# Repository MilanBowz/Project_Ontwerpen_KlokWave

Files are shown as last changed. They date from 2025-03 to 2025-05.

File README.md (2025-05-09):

# PO_KlokWave

## Altium

### Extra info: [Info map](Info)
- BOM
- [WAVE (alarm) source](Info/WAVE.zeewatersportsynthesizer.pdf)

### PIN mapping Arduino - ATMEGA
Gebruikt voor logica te programmeren.
https://www.circuito.io/blog/arduino-uno-pinout/

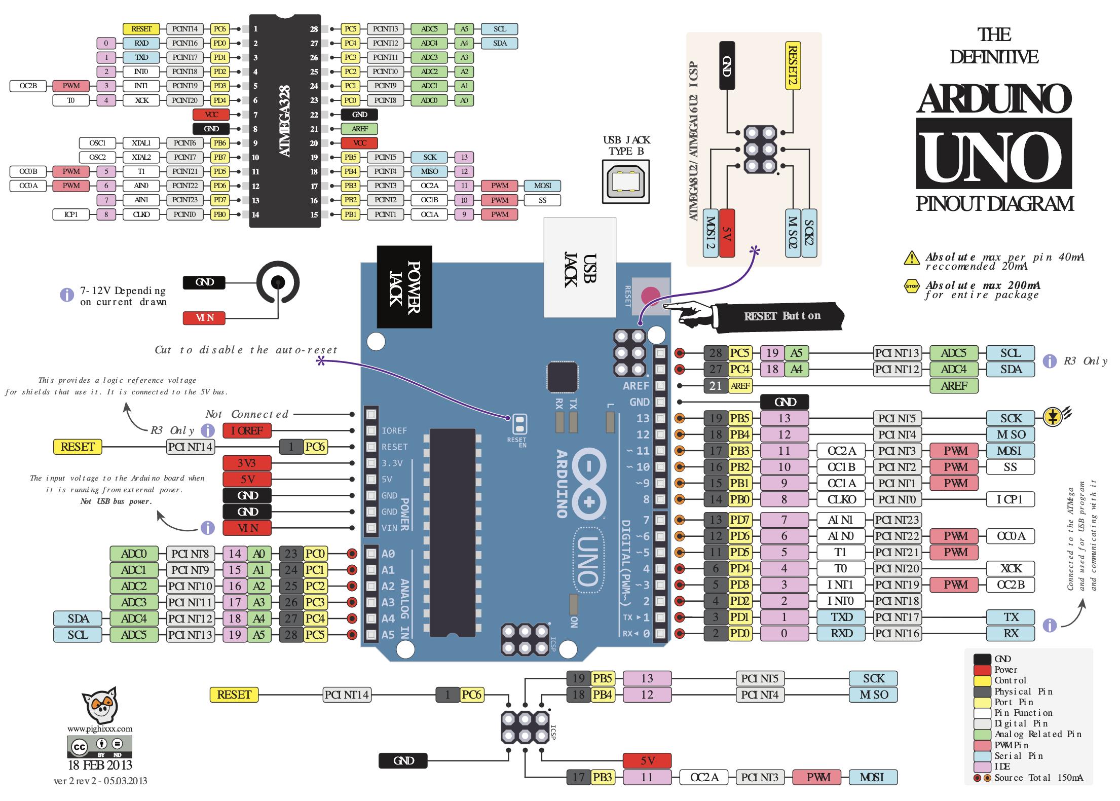
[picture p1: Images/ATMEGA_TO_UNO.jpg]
ATMEGA pins


### 8-Bit schuifregister
Gebruikt om aantal I/O pinnen in gebruikt van ATMEGA.
- hardwaretest met 7-segment display (/Tests)

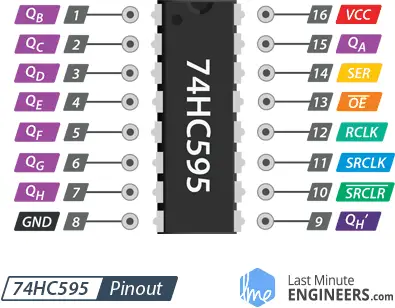
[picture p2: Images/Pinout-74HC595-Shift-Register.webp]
74HC595 pins


### Alarm (clock/ATMEGA output PB2)

Video tutorial BC547: https://www.youtube.com/watch?v=-o46f7fIX9A

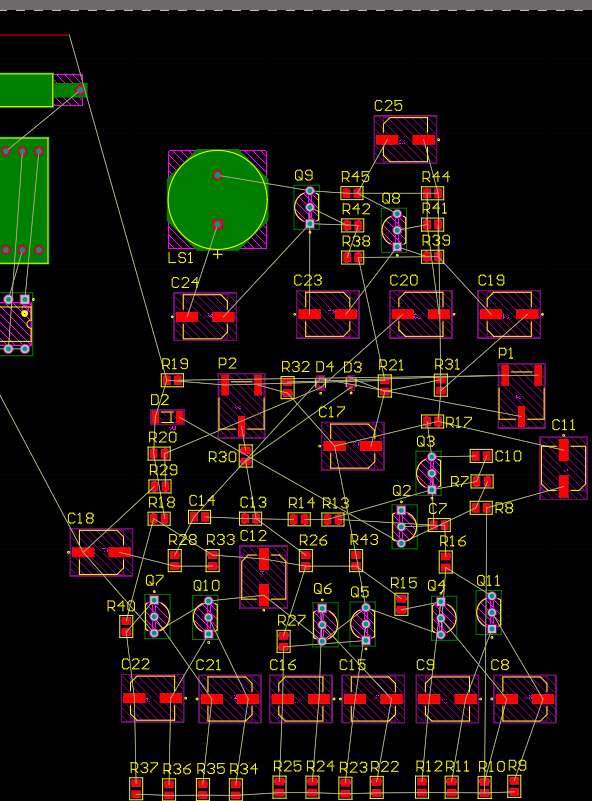
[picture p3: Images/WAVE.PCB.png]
WAVE ALARM PCB design in Altium
 

## Autodesk / 3D.Design

The design needs 2 types of holes:
- Power Supply
- Scew holes for PCB and lid

Lid is made of "~ invisible" plastic.

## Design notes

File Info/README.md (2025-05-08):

## 📦 Bill of Materials (BOM)

| **Part Number** | **Description / Value** | **Designators** | **Qty** | **Supports** |
|---|---|---|---|---|
| CR-2032/HFN | THT Coin Cell Battery, 3V, 225 mAh | B1 | 1 | DS1307+ VBAT |
| 16SEPC150MD | THT OS-CON Radial Capacitor (Polarised) | C1, C2 | 2 | VCC |
| | 220µF | C1, C2 | 2 | |
| 565R30GASS33 | THT Ceramic Capacitor (not polarised) | C3–C6 | 4 | ATMEGA |
| | 100nF | C3, C4 | 2 | VCC |
| | 22pF | C5, C6 | 2 | Y1 Crystal |
| CL21 Series 0805 | SMD 0805 Ceramic Capacitor (not polarised) | C7, C10, C13, C14 | 4 | ALARM (see pdf) |
| | 220nF, 100nF, 47nF, 4.7nF | | 4x1 | |
|  FP-OS-CON-SMT-C6-MFG | SMD Elco Capacitor (polarised) | C8–C12, C15–C25 | 15 | |
| | 100µF / 16V | | 4 | |
| | 47µF / 16V | | 6 | |
| | 10µF / 16V | | 5 | |
| 1N4007-E3/53 | THT Diode, 1A 1kV DO204AL | D1 | 1 | |
| TMMBAT48FILM | SMD Schottky Diode 40V 350mA | D2 | 1 | |
| 1N4148WT-7 | SMD Diode, 80V 125mA | D3, D4 | 2 | |
| HLMP-3301 | THT 5mm Diffused LED | DS2 | 1 | |
| — | THT DC Power Jack | J1 | 1 | |
| SA56-11EWA | THT 7-Segment Display CA | LED1–LED4 | 4 | |
| CVS-1508 | THT Speaker | LS1 | 1 | |
| 3361P-1-503GLF | SMD Trimmer Potentiometer, 50kΩ | P1, P2 | 2 | |
| BC547C | NPN Transistor, TO-92 | Q1–Q11 | 11 | |
| AC03000003000JAC00 | THT Wirewound Resistor | R3–R6, R46–R50 | 9 | |
| | 10kΩ | R5, R6, R50 | 3 | SDA, SCL, RESET |
| | 1kΩ | R4 | 1 | CTRL_ALARM |
| | 330Ω | R3 | 1 | TEST_LED |
| | 220Ω | R46–R49 | 4 | DISPLAY |
| CR0805-FX-22R6ELF | SMD 0805 Resistor | R7–R45 | 39 | ALARM (see pdf) |
| | Values: 1M, 680k, 270k, 180k, 100k, 68k (×9), 47k (×4), 39k (×2), 33k, 22k (×2), 10k (×3), 6.8k (×6), 4.7k, 2.2k, 1k, 680Ω, 560Ω, 470Ω, 100Ω | 
| 1825910-6 | THT Tactile Switch SPST-NO | SW1–SW4 | 4 | |
| ATmega328P-PU | THT AVR Microcontroller 28-pin PDIP | U1 | 1 | |
| LM7805 | THT 5V Voltage Regulator TO-220 | U2 | 1 | |
| 74HC595N | THT 8-bit Shift Register | U3, U5–U7 | 4 | |
| DS1307+ | THT I2C RTC, 8-pin PDIP | U4 | 1 | |
| 16MHz Crystal HC49 | THT Quartz Crystal (ATmega) | Y1 | 1 | |
| 32.768kHz Crystal | THT Crystal, 12.5pF (DS1307+) | Y2 | 1 | |

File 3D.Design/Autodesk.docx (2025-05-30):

# Autodesk-3D

Top-Right-Front:

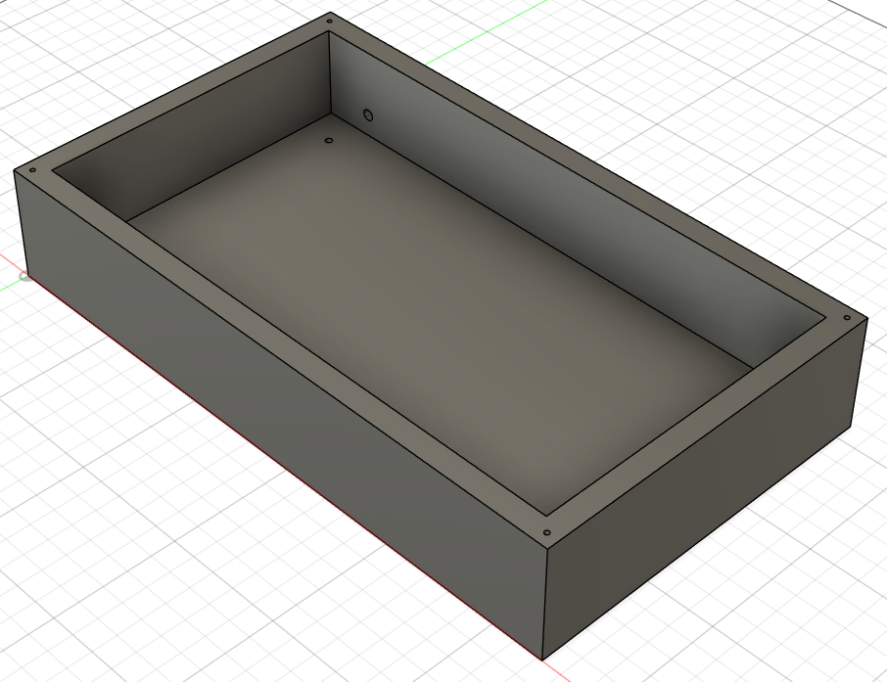
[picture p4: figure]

Back-Left-Top:

- gat voor power supply

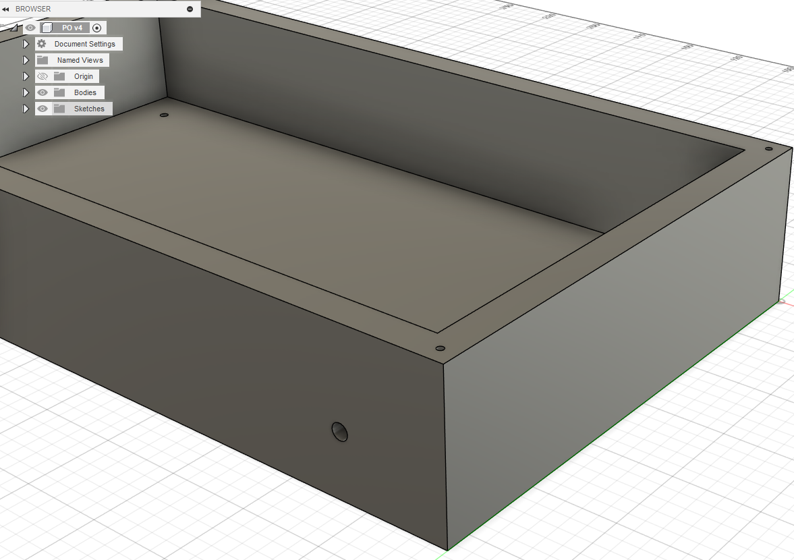
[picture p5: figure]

Top:

- Gaten voor PCB vast te maken
- Gaten voor mogelijks deksel vast te maken (easy mode)

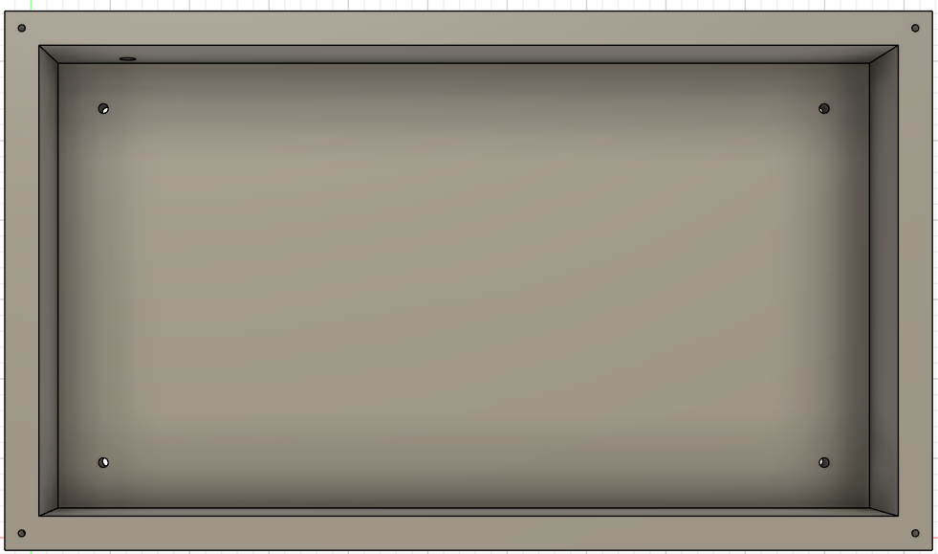
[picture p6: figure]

Materiaal:

- Plexiglas als behuizing
- M3 schroeven voor PCB vast te maken
- 2.9 diameter schroeven voor stoelhoek
- Smalle scharnier ( deksel case open- & toedoen )
- Stoelhoek om plexiglas te verbinden

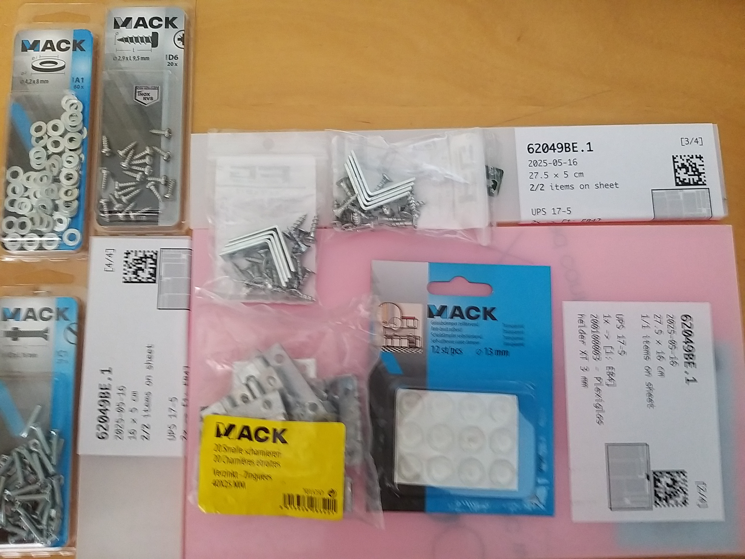
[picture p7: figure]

- Geluidsdemper zelfklevend voor op grondvlak (bescherming grondvlak plexiglas)

Technische tekening: ( zie ook: PO_case.pdf )

- De dikte van de wanden zijn veranderbaar
- Exacte positie voor gaten t.o.v. de buitenwanden worden pas geboord wanneer pcb aangekomen is.
1. Alles is uitgedrukt in mm:
  a. De afstand v/d gaten voor de pcb is altijd 223.87 & 109.87
  b. De hoogte in de binnenkant v/d case moet minstens 40 zijn
  c. Boorgaten v/d pcb zijn 3
  d. Rest zijn voorbeeldmaten met behuizingdikte 10

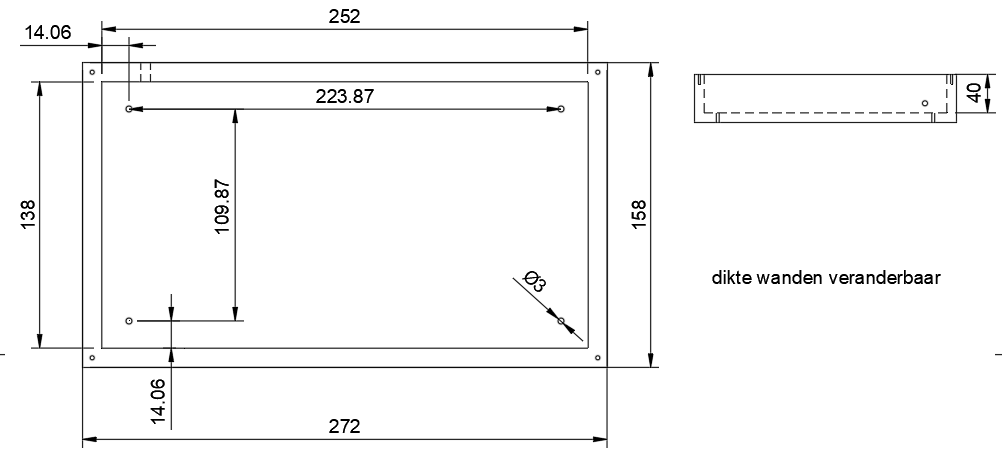
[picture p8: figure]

User Parameters:

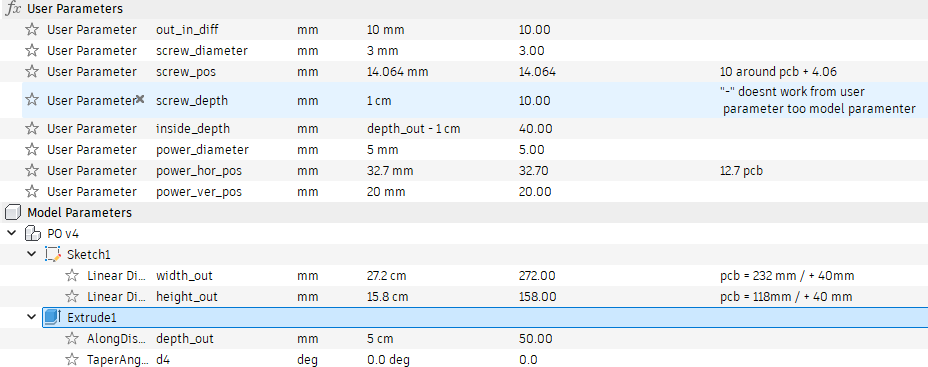
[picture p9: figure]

Milan Posman

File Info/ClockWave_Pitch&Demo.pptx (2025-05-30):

## Pitch ClockWave

Milan Posman

## Do you like beaches ?

- El Campello, Spain
  - Sound of gentle waves
  - Warm sun
  - Local markets
  - Swimming
No stress

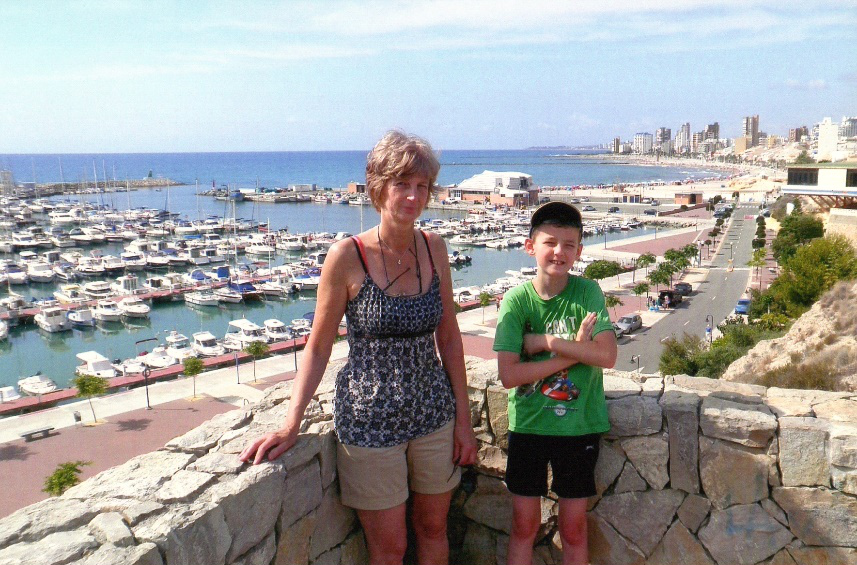
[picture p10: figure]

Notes: Every year, I visit a small beach town called El Campello, in Spain.
There, I wake up to the sound of gentle waves, the warm sun rising over the sea. We visit local markets, i swim in the ocean/pool …
No stress, Just peace.

## Do you miss the beaches ?

When you come home …
- Cold, humid weather
- Stress
- Aggressive sounds

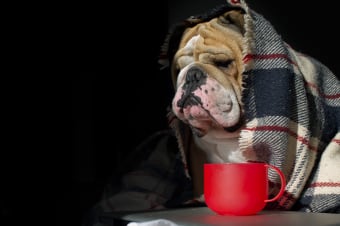
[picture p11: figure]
Dog Depression, Dog Anxiety, and Dog Nerves - Is my dog depressed?

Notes: But when I came home — and reality hit fast.
Cold, humid mornings
Stress
& worst of all: all those aggressive sounds wake you up like a punch in the face.

## Introducing … ClockWave !

Alarm Clock
- Custom - designed hardware
- Accurate real time clock
- Relaxing ocean waves

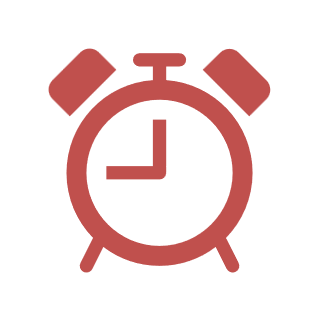
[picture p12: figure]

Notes: That’s why I created ClockWave, an alarm clock that:
Is custom designed hardware
With an accurate real time clock
That wakes you up gently with an speaker plays the ocean waves at alarm time

## Demo ClockWave

Milan Posman

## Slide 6

- 3 parts

1. Power supply
2. Clock
3. Wave (alarm)

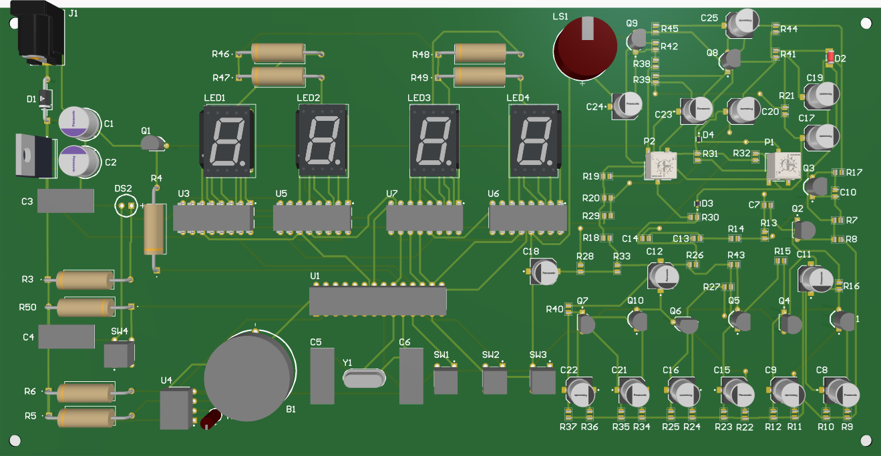
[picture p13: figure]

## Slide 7

- User Interactions

- Power supply
- MODE, + & - button
- Wave interaction

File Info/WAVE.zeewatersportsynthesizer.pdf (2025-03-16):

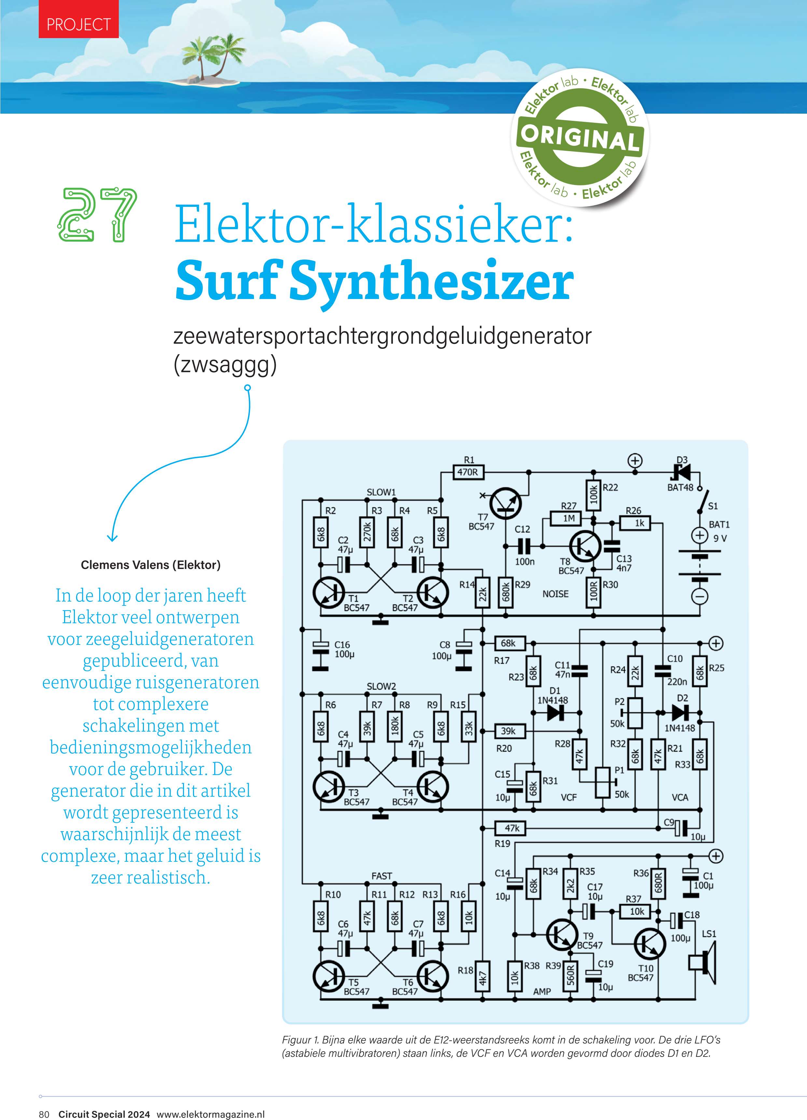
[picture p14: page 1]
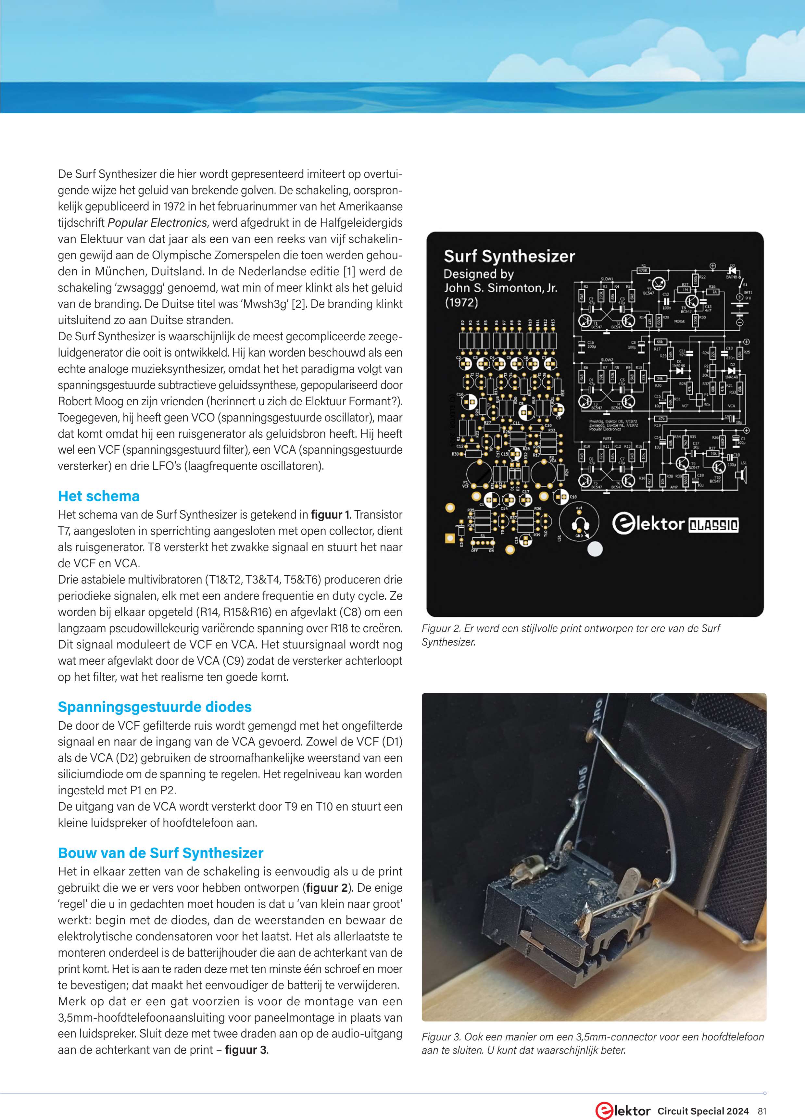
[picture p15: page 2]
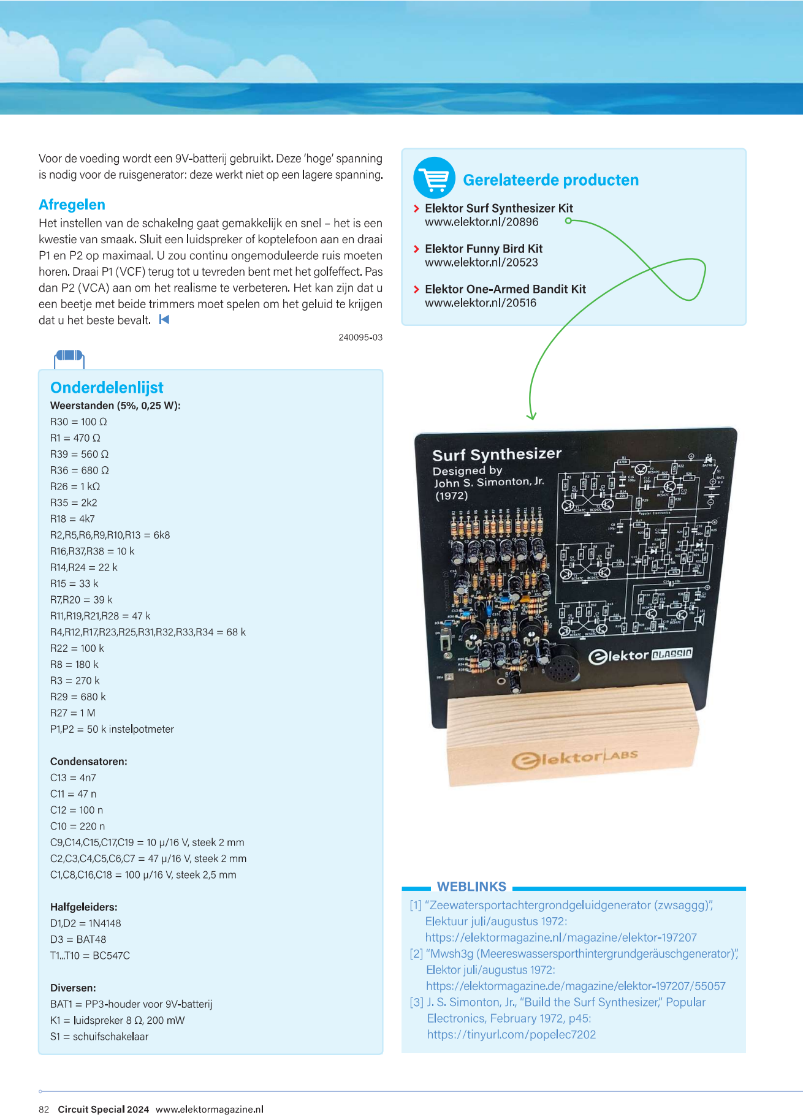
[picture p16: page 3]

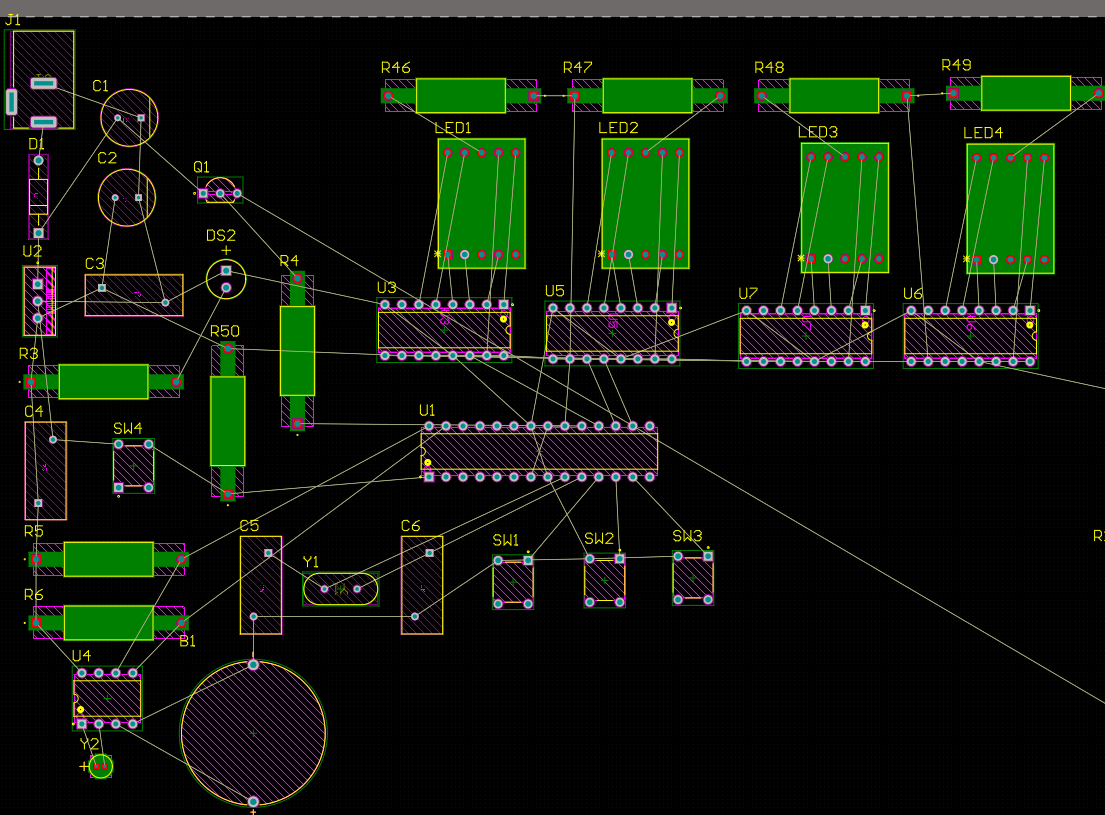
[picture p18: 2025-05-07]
Images/CLOCK.PCB.png

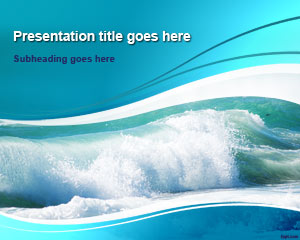
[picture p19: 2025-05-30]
Info/2952-ocean-waves-powerpoint-template.jpg

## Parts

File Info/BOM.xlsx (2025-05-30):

Part Number | Description / Value | Designators | # | Supports ?
CR-2032/HFN | THT Coin Cell Battery, 3V, 225 mAh | B1 | 1 | DS1307+ VBAT
16SEPC150MD | THT OS-CON Radial Capacitor (Polarised) | C1, C2 | 2 | VCC
 | 220µF | C1, C2 | 2
565R30GASS33 | THT Ceramic Capacitor (Not polarised) | C3-C6 | 4 | ATMEGA
 | 100nF | C3-C4 | 2 | VCC
 | 22pF | C5, C6 | 2 | Y1 Crystal
CL21 Series 0805 | SMD 0805 Ceramic Capacitor (Not Polarised) | C7, C10, C13, C14 | 4 | ALARM
 | 220nF |  | 1
 | 100nF |  | 1
 | 47nF |  | 1
 | 4n7F |  | 1
FP-OS-CON-SMT-C6-MFG | SMD Elco Capacitor (Polarised) | C8–C12, C15–C25 | 15
 | 100µF / 16 V |  | 4
 | 47µF / 16 V |  | 6
 | 10 µF / 16 V |  | 5
1N4007-E3/53 | THT 1A 1kV Diode DO204AL | D1 | 1
TMMBAT48FILM | SMD Schottky Diode 40V 350mA | D2 | 1
1N4148WT-7 | SMD General Purpose Diode 80V 125mA | D3, D4 | 2
HLMP-3301 | THT 5mm Diffused LED THT | DS2 | 1
— | THT DC Power Jack | J1 | 1
SA56-11EWA | THT 7-Segment Display CA | LED1–LED4 | 4
CVS-1508 | THT Speaker | LS1 | 1
3361P-1-503GLF | SMD Trimmer Pot / 50KE | P1, P2 | 2
BC547C | NPN Transistor TO-92 | Q1–Q11 | 11
AC03000003000JAC00 | THT Wirewound Resistor | R3–R6, R46–R50 | 9
 | 10KE | R5, R6, R50 | 3 | SDA,SCL,RESET
 | 1KE | R4 | 1 | CTRL_ALARM
 | 330E | R3 | 1 | TEST_LED
 | 220E | R46-R49 | 4 | DISPLAY
CR0805-FX-22R6ELF | SMD 0805 Resistor | R7–R45 | 39 | ALARM
 | 1ME |  | 1
 | 680KE |  | 1
 | 270KE |  | 1
 | 180KE |  | 1
 | 100KE |  | 1
 | 68KE |  | 9
 | 47KE |  | 4
 | 39KE |  | 2
 | 33KE |  | 1
 | 22KE |  | 2
 | 10KE |  | 3
 | 6K8E |  | 6
 | 4K7E |  | 1
 | 2K2E |  | 1
 | 1KE |  | 1
 | 680E |  | 1
 | 560E |  | 1
 | 470E |  | 1
 | 100E |  | 1
1825910-6 | THT Tactile Switch SPST-NO | SW1–SW4 | 4
ATmega328P-PU | THT AVR Microcontroller 28-pin PDIP | U1 | 1
LM7805 | THT 5V Voltage Regulator TO-220 | U2 | 1
74HC595N | THT 8-bit Shift Register | U3, U5–U7 | 4
DS1307+ | THT I2C RTC, 8-pin PDIP | U4 | 1
16MHz Crystal HC49 | THT Quartz Crystal HC49 16MHz (for ATMEGA) | Y1 | 1
32.768kHz Crystal | THT Crystal, 12.5pF 32.768kHz ( for DS1307+) | Y2 | 1

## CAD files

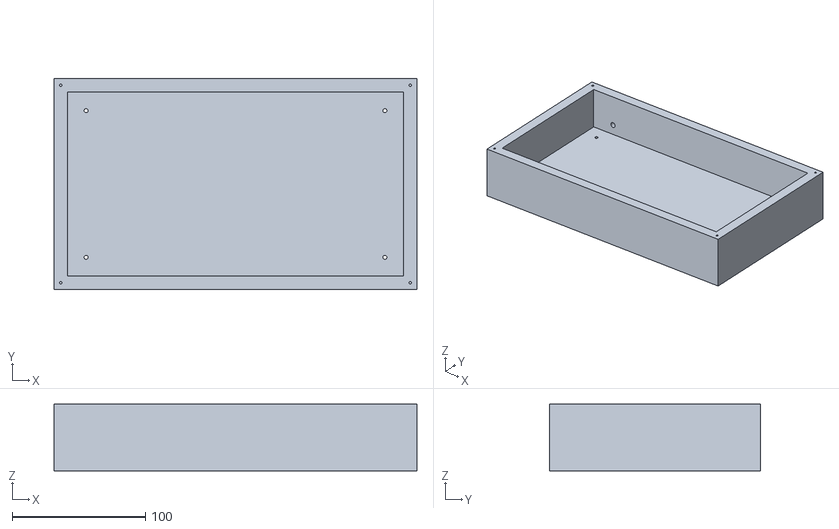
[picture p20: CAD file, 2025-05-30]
3D.Design/PO v6.stl
272.0 x 158.0 x 50.0

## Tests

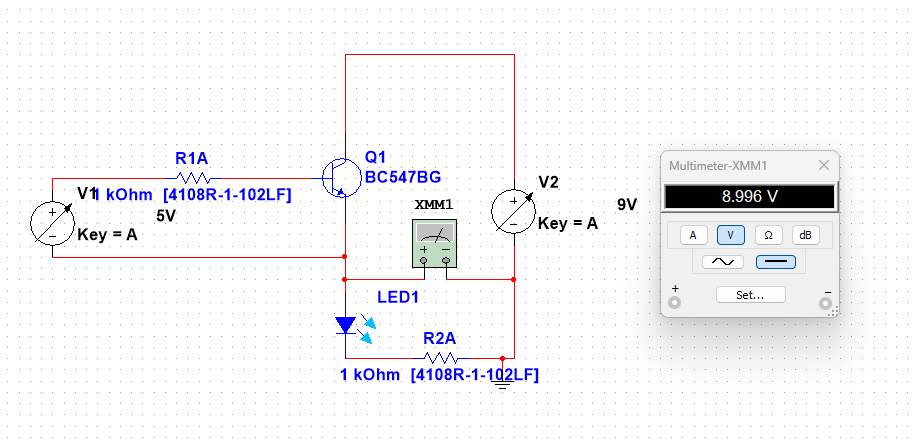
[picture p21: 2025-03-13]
Tests/PB5.ALARM/BC547C_BC847B.image01.png

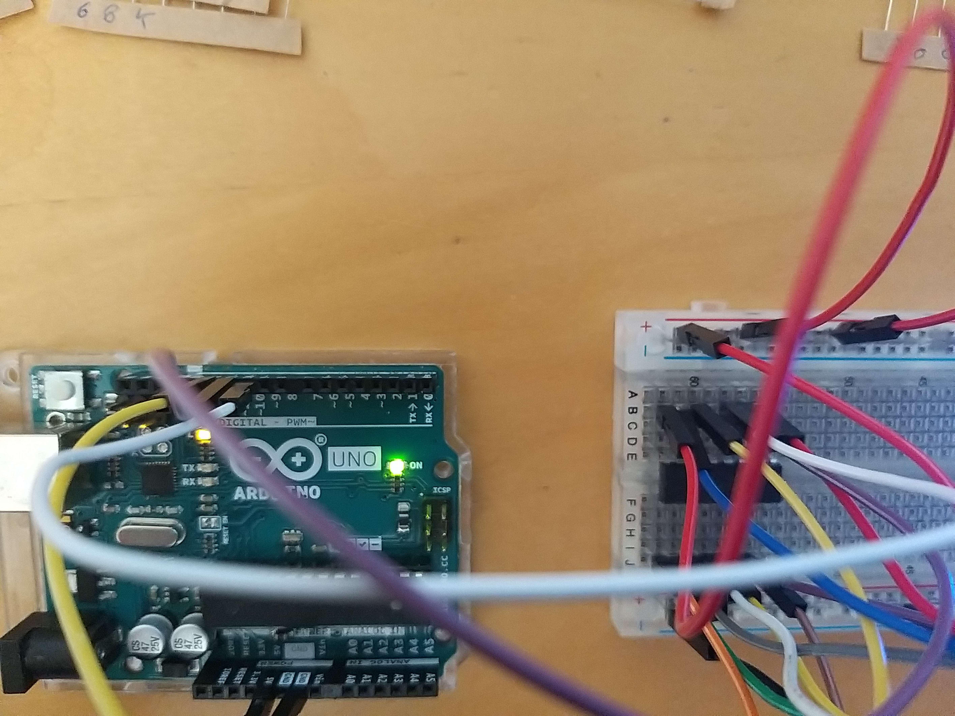
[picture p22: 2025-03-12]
Tests/Schuifregister/74HC595N.image03.jpg

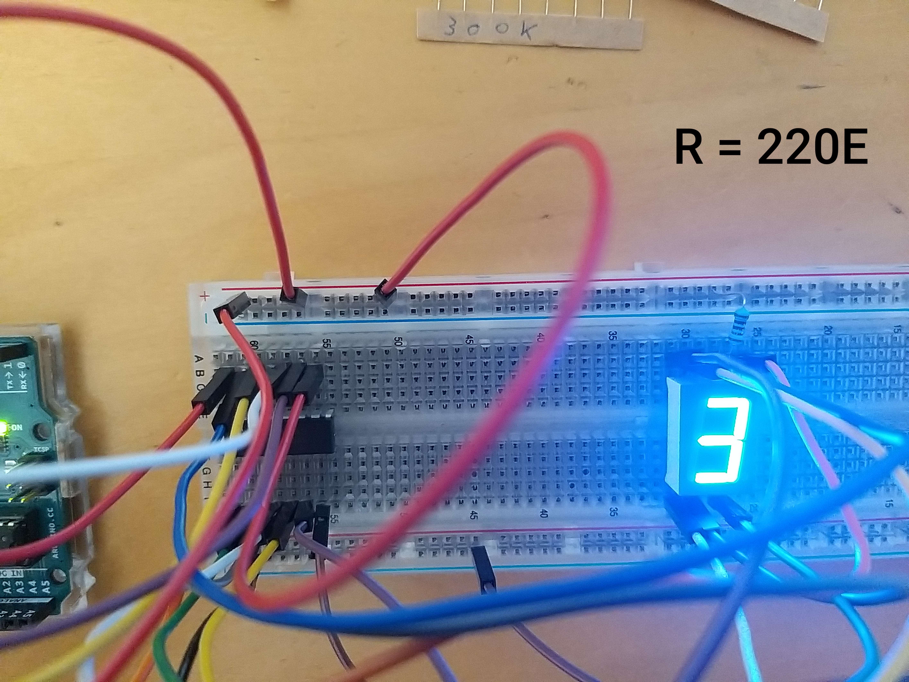
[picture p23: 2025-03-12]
Tests/Schuifregister/74HC595N.image04.jpg

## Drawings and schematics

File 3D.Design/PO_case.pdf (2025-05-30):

138 | 14.06 272 | 252 223.87

14.06

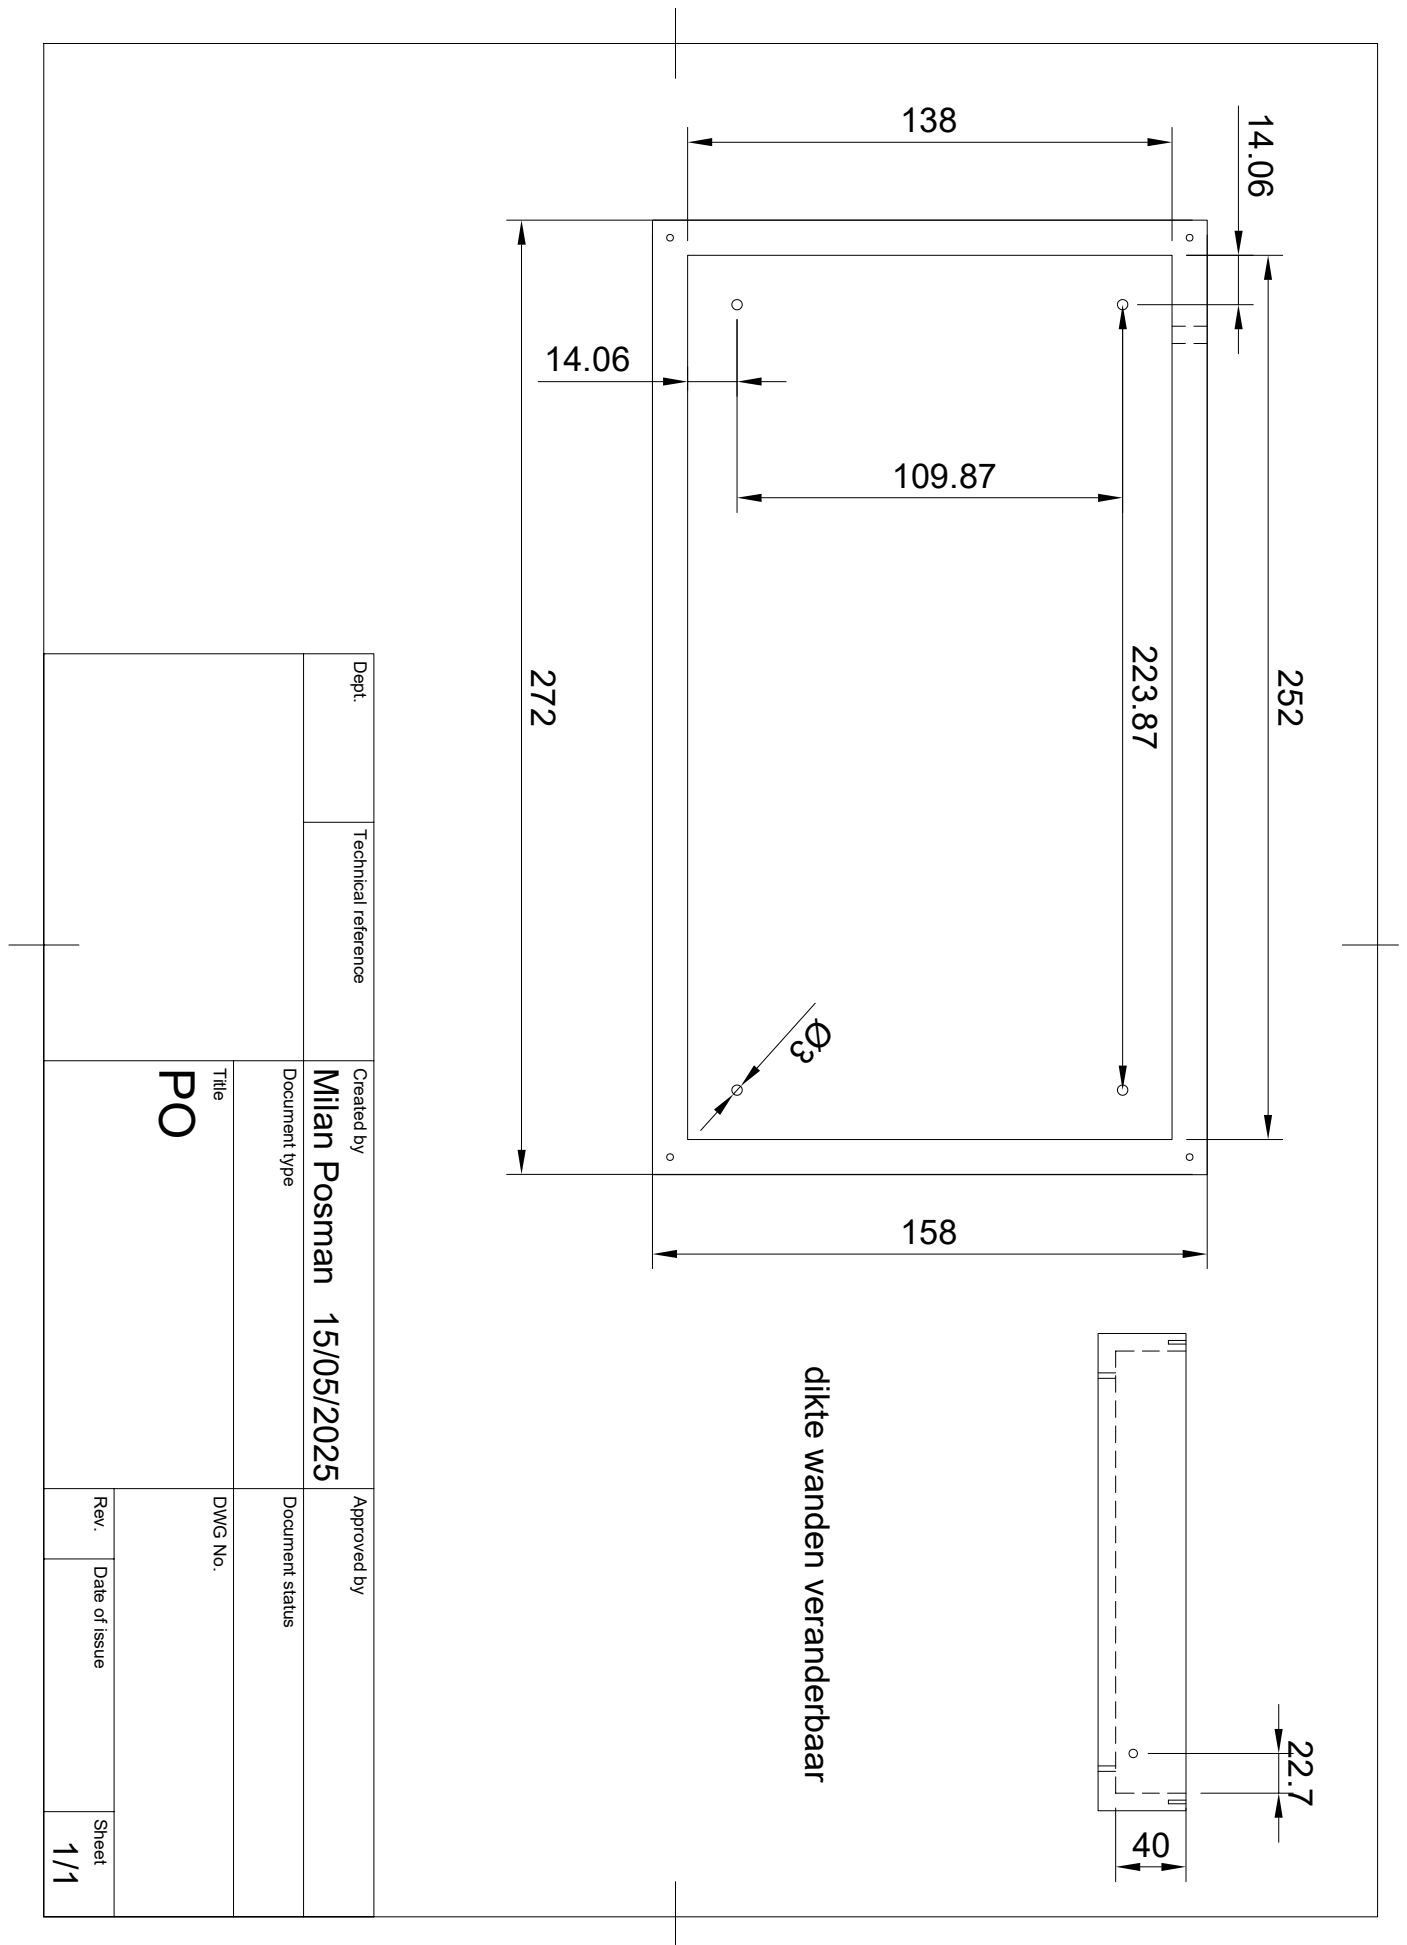
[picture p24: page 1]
40 dikte wanden veranderbaar

Dept. Technical reference Created by Approved by Title DWG No. Document type Document status Rev. Date of issue Sheet 15/05/2025 1/1 POMilan Posman158

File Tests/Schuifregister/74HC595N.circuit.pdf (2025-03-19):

A

1 | 2 | 3 | 4 | 5 | 6

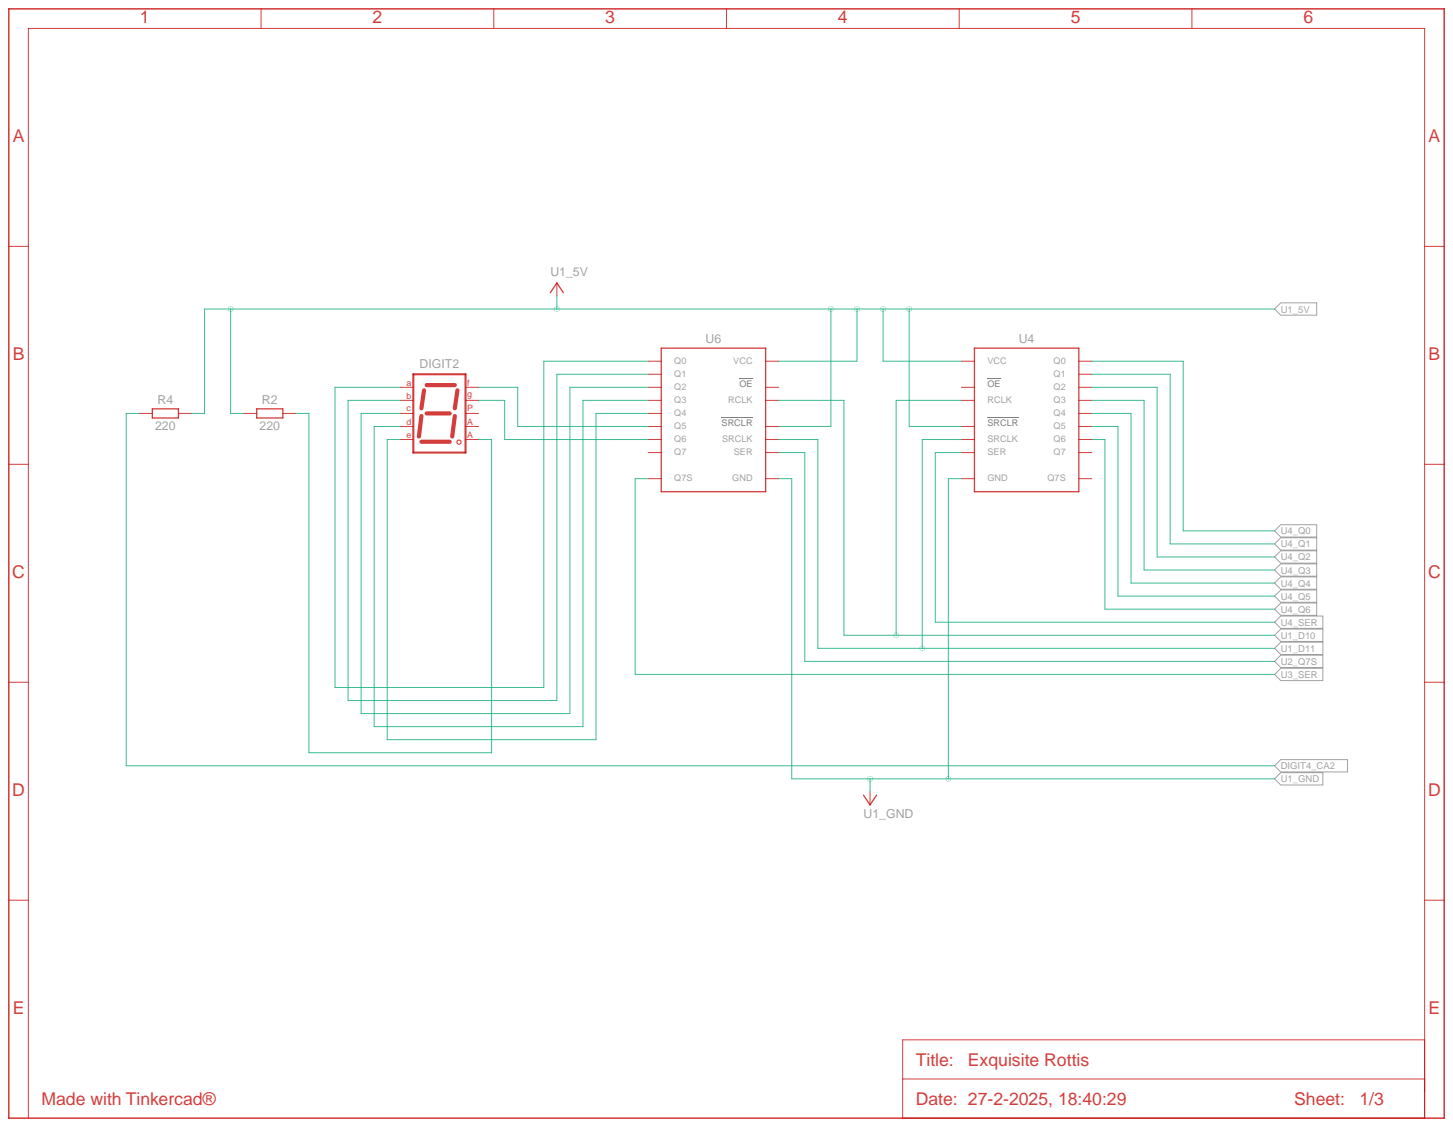
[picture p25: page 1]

c | P A A

A

1 | 2 | 3 | 4 | 5 | 6

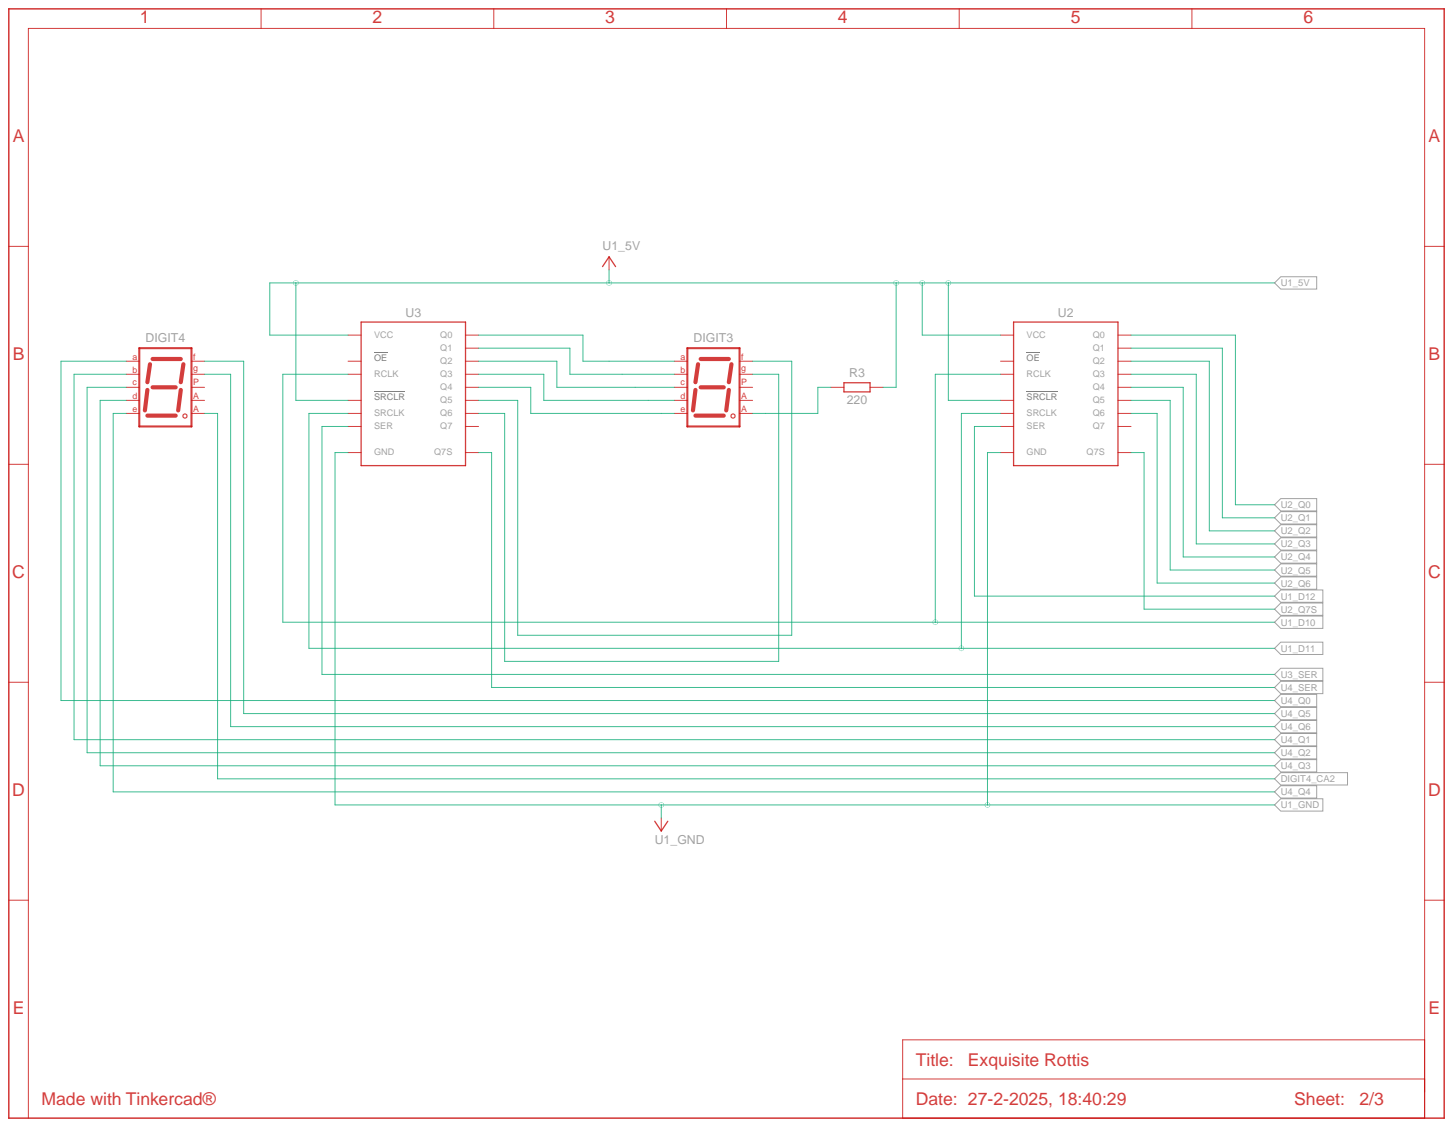
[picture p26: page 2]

A

1 | 2 | 3 | 4 | 5 | 6

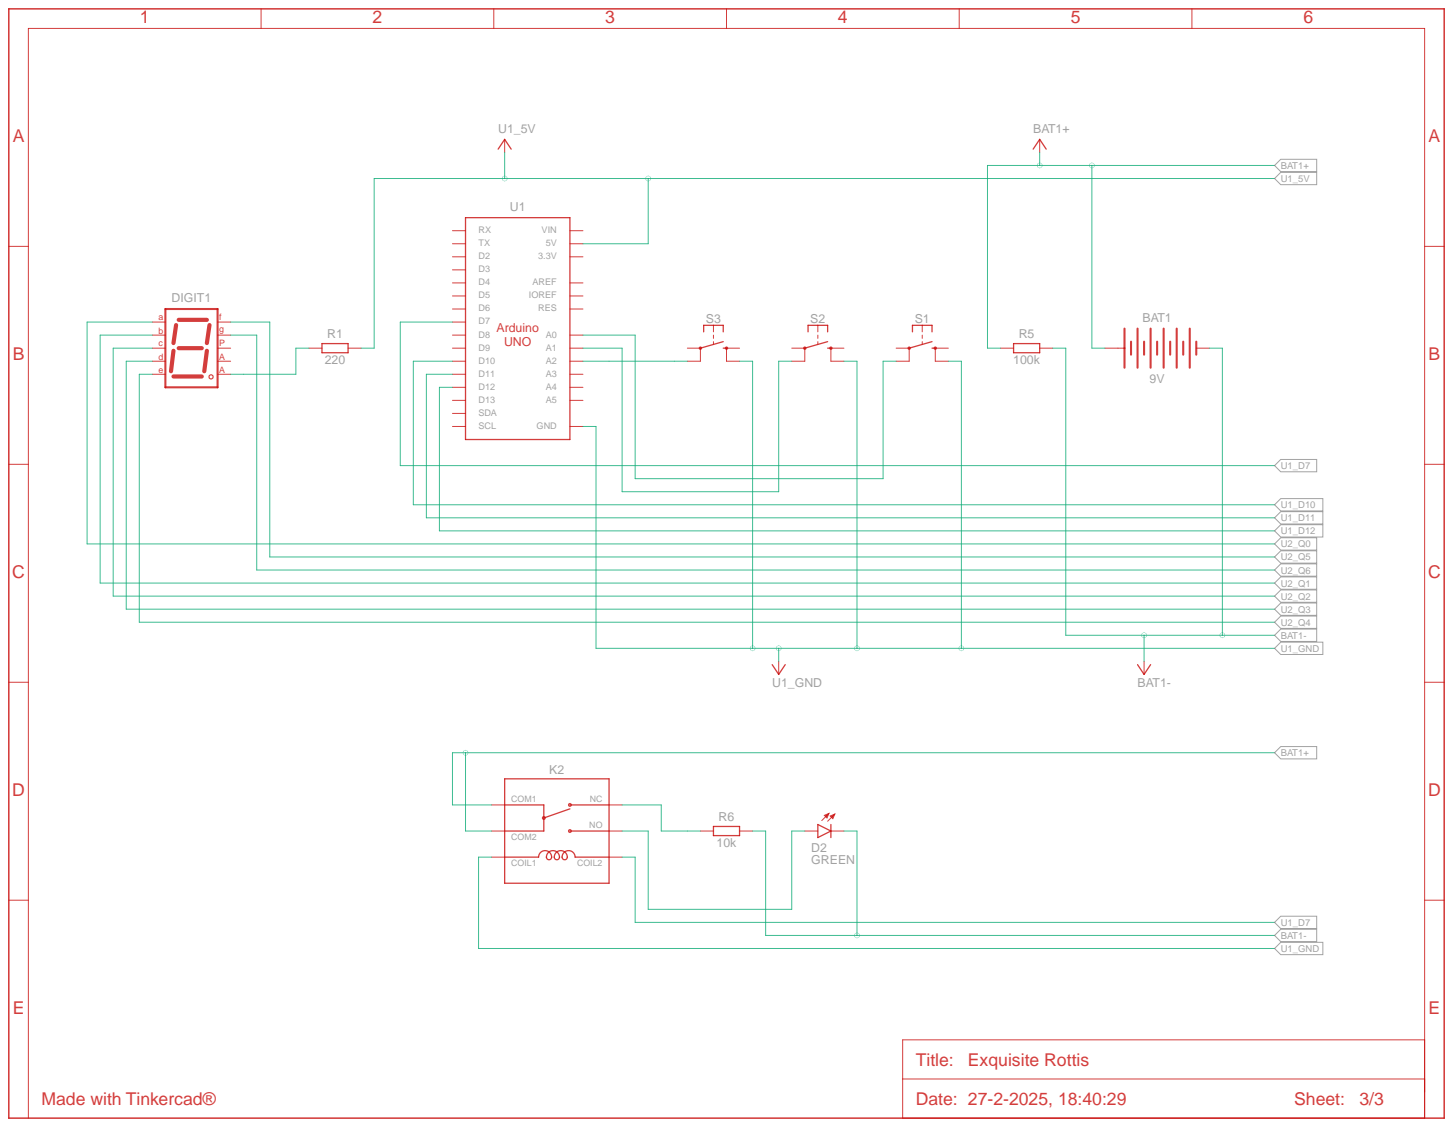
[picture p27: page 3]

c | P A A

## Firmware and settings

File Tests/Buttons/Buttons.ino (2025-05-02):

// Pin definitions (PD5, PD6, PD7)
const int button1Pin = 5;  // PD5
const int button2Pin = 6;  // PD6
const int button3Pin = 7;  // PD7

void setup() {
  // Use internal pull-up resistors (external connected via Ground)
  pinMode(button1Pin, INPUT_PULLUP);
  pinMode(button2Pin, INPUT_PULLUP);
  pinMode(button3Pin, INPUT_PULLUP);
  Serial.begin(9600);
}

void loop() {
  // Read button states (LOW = pressed, HIGH = not pressed)
  bool btn1 = digitalRead(button1Pin) == LOW;
  bool btn2 = digitalRead(button2Pin) == LOW;
  bool btn3 = digitalRead(button3Pin) == LOW;

  // Print to Serial Monitor
  Serial.print("BTN1: ");
  Serial.print(btn1);
  Serial.print(" | BTN2: ");
  Serial.print(btn2);
  Serial.print(" | BTN3: ");
  Serial.println(btn3);

  delay(200); // Delay for readability
}

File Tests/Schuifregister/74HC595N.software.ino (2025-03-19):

/*
  74HC595 Shift Register with 7-segment LED display
  74hc595-7segdisplay.ino
  Display on 7-segment Common Cathode LED display

  DroneBot Workshop 2020
  https://dronebotworkshop.com
*/

// Define Connections to 74HC595
//#include "RTClib.h"

// RCLK pin 12
const int latchPin = 10;
const int latchPinDec = 9;
// SH_CP pin 11
const int clockPin = 11;
// DS pin 14 / INVOER /
const int dataPin = 12;

// Time tracking
unsigned long previousMillis = 0;
const long interval = 1000; // 1 second
int hours = 12, minutes = 0, seconds = 0;

// Inverted patterns for characters 0-9
int datArray[10] = {0B11000000,  // 0
                    0B11111001,  // 1
                    0B10100100,  // 2
                    0B10110000,  // 3
                    0B10011001,  // 4
                    0B10010010,  // 5
                    0B10000010,  // 6
                    0B11111000,  // 7
                    0B10000000,  // 8
                    0B10010000}; // 9


const int buttonPin = A0;
const int buttonPin2 = A1;
const int buttonPin3 = A2;
const int buttonOut = 7;


void setup ()
{
  Serial.begin(57600);
  // Setup pins as Outputs
  pinMode(latchPin, OUTPUT);
  pinMode(clockPin, OUTPUT);
  pinMode(dataPin, OUTPUT);
  pinMode(buttonPin, INPUT_PULLUP);
  pinMode(buttonPin2, INPUT_PULLUP);
  pinMode(buttonPin3, INPUT_PULLUP);
  pinMode(buttonOut, OUTPUT);
}
void loop()
{
  // Simulate clock using millis()
  unsigned long currentMillis = millis();
  if (currentMillis - previousMillis >= interval) {
    previousMillis = currentMillis;
    seconds++;
    if (seconds >= 60) {
      seconds = 0;
      minutes++;
      if (minutes >= 60) {
        minutes = 0;
        hours++;
        if (hours >= 24) hours = 0;
      }
    }
  }
  // Read button state with debouncing
  if (digitalRead(buttonPin) == LOW) {
    digitalWrite(buttonOut, HIGH);
    Serial.println("Button Pressed!");
    delay(200); // Debounce
  }
  else{
    digitalWrite(buttonOut, LOW);
    Serial.println("Button Released!");
    delay(200); // Debounce
  }
  if (digitalRead(buttonPin2) == LOW) {
    Serial.println("Button 2 Pressed!");
    delay(200); // Debounce
  }
  if (digitalRead(buttonPin3) == LOW) {
    Serial.println("Button 3 Pressed!");
    delay(200); // Debounce
  }
  // ST_CP LOW to keep LEDs from changing while reading serial data
  // Shift out the bits
  digitalWrite(latchPin, LOW);
  //shiftOut(dataPin, clockPin, MSBFIRST, datArray[seconds % 10]);
  //shiftOut(dataPin, clockPin, MSBFIRST, datArray[seconds / 10]);
  //shiftOut(dataPin, clockPin, MSBFIRST, datArray[minutes % 10]);
  shiftOut(dataPin, clockPin, MSBFIRST, datArray[seconds % 10]);
  // ST_CP HIGH change LEDs
  digitalWrite(latchPin, HIGH);
}

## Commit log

2025-03-04 add altium files
    [KlokWave.SchDoc, KlokWave.SchLib, Project_Ontwerpen.PrjPcb]
2025-03-06 added quartz
    [KlokWave.SchDoc, KlokWave.SchLib]
2025-03-12 test schuifregister
    [KlokWave.SchDoc, Project_Ontwerpen.PrjPcb, Zswagg.SchDoc]
2025-03-13 ALARM + zswag part 1
    [KlokWave.SchDoc, Zswagg.SchDoc]
2025-03-16 Wave AMP + 1/2 VCF
    [KlokWave.SchLib, Zswagg.SchDoc]
2025-03-16 renaming schematic files
    [KlokWave.Klok.SchDoc, KlokWave.Wave.SchDoc]
2025-03-19 toevoegen tinkercad test schuifregister
    [bom_tinkercad.csv]
2025-03-20 + 7 segment displays of clock
    [KlokWave.Display.SchDoc, KlokWave.Klok.SchDoc, KlokWave.SchLib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]
2025-03-20 added button to operate clock/alarm + battery for DS1307
    [KlokWave.Display.SchDoc, KlokWave.Klok.SchDoc, KlokWave.SchLib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]
2025-03-20 updated project
    [Project_Ontwerpen.PrjPcb]
2025-03-21 begin pcbDesign + bomdoc + reset button
    [KlokWave.Display.SchDoc, KlokWave.Klok.SchDoc, KlokWave.Wave.SchDoc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]
2025-03-28 footprint update to schematic
    [KlokWave.Klok.SchDoc, KlokWave.SchLib, KlokWave.Wave.SchDoc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]
2025-03-31 footprint transistor THT change
    [KlokWave.SchLib, Project_Ontwerpen.PrjPcb]
2025-04-04 schematic make ATMEGA ports bidirectional
    [KlokWave.Klok.SchDoc, KlokWave.PcbDoc, KlokWave.SchLib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]
2025-04-04 fix power i/o for atmega,...
    [KlokWave.Display.SchDoc, KlokWave.Klok.SchDoc, KlokWave.PcbDoc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]
2025-05-02 pcb board part 1
    [KlokWave.Display.SchDoc, KlokWave.Klok.SchDoc, KlokWave.PcbDoc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]
2025-05-03 pcb board part 2: SMD begin
    need to check max values for SMD technology
    [KlokWave.Klok.SchDoc, KlokWave.PcbDoc, KlokWave.PcbLib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]
2025-05-03 pcb board part 3: ready for control
    [KlokWave.PcbDoc, KlokWave.Wave.SchDoc]
2025-05-05 BOM in office + pcb board part 4: control with BOM
    [BOM.xlsx, KlokWave.Display.SchDoc, KlokWave.Klok.SchDoc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]
2025-05-06 BOM update
    [BOM.xlsx]
2025-05-06 Create README.md
    bom README TEST
2025-05-07 added images pcb (temp: name is same)
2025-05-07 polarised capacitors are not 0805 anymore
    they are now elco capacitors (pcb image still needs updated)
    [BOM.xlsx, KlokWave.PcbDoc, KlokWave.PcbLib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]
2025-05-08 naming standard
    [BOM.xlsx, KlokWave.PcbDoc, KlokWave.PcbLib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]
2025-05-09 update pcb design criteria
    [KlokWave.Display.SchDoc, KlokWave.Klok.SchDoc, KlokWave.PcbDoc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]
2025-05-15 3D design height,width,...
    [KlokWave.Klok.SchDoc, KlokWave.PcbDoc, KlokWave.PcbLib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]
2025-05-30 final commit for PO
    [BOM.xlsx, KlokWave.PcbDoc, PO v4.stl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]
